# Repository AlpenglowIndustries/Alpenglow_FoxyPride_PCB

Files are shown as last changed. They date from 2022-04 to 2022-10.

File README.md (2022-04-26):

# Foxy_Pride_PCB
An awesome SMT soldering board with space for writing pronouns, where you can choose your own pride-themed colors for the LEDs.
The circuit uses a 555 timer to create a clock signal, which is fed into the decade counter to light the LEDs.
You can change the blink rate by swapping out the capacitor!

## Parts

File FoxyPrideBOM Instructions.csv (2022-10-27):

Id | Designator | Package | Qty Kit | Qty | Description | Manufacturer | Manufacturer Part Number
1 | BT1, | Alpenglow:BatteryHolder_CR2032_SMT | 1 | 1 | Battery holder, side slide style, smt | Hongkong RTL | BK-912
2 | C1, C3, | C_SMD:R_1206_3216Metric_Pad1.30x1.75mm_HandSolder | 2 | 2 | 0.01 uF / 10 nF ceramic chip capacitor, 50V X7R ±10% 1206 | CCTC | TCC1206X7R103K500DTS
3 | C2, C4, | C_SMD:R_1206_3216Metric_Pad1.30x1.75mm_HandSolder | 2 | 2 | 0.1 uF / 100 nF ceramic chip capacitor, 50V X7R ±20% 1206 | CCTC | TCC1206X7R104M500DT
4 | D1, D2, D3, D4, D5, D6, D7, D8, D9, D10, | Alpenglow:LED_1206+ | 5 | 1 | White LED, 25mA 90mcd 2.8V 13700K~19000K Yellow -30℃~+85℃ Positive post White light 120° 80mW 1206 | XINGLIGHT | XL-3216UWC
5 |  | Alpenglow:LED_1206+ | 5 | 1 | Yellow LED, 25mA 130mcd 2.1V 593nm Colorless transparence -30℃~+85℃ 589nm~591nm Positive post yellow 120° 55mW 1206 | XINGLIGHT | XL-3216UYC
6 |  | Alpenglow:LED_1206+ | 5 | 1 | Blue LED, 25mA 60mcd 2.8V 475nm Colorless transparence -30℃~+85℃ Positive post 460nm~469nm blue 120° 80mW 1206 | XINGLIGHT | XL-3216UBC
7 |  | Alpenglow:LED_1206+ | 5 | 1 | Orange LED, 25mA 90mcd 2.1V 605nm Colorless transparence -30℃~+85℃ 601nm~603nm Positive post Orange 120° 55mW 1206 | XINGLIGHT | XL-3216UOC
8 |  | Alpenglow:LED_1206+ | 5 | 1 | Red LED, 25mA 45mcd 1.95V 623nm Colorless transparence -30℃~+85℃ Positive post 617nm~621nm Red 120° 55mW 1206 | XINGLIGHT | XL-3216SURC
9 |  | Alpenglow:LED_1206+ | 5 | 1 | Green LED, 25mA 173mcd 2.9V 534nm Colorless transparence 516nm~525nm -30℃~+85℃ Positive post Emerald 120° 80mW 1206 | XINGLIGHT | XL-3216UGC
10 |  | Alpenglow:LED_1206+ | 5 | 1 | Purple LED | XIASONGXIN LIGHT | SX-1206-5-COLOR
11 |  | Alpenglow:LED_1206+ | 5 | 2 | Pink LED | XIASONGXIN LIGHT | SX-1206-PINK
12 |  | Alpenglow:LED_1206+ | 5 | 1 | Ice Blue / cyan LED | XIASONGXIN LIGHT | 1206 ICE BLUE
13 | R11 | R_SMD:R_1206_3216Metric_Pad1.30x1.75mm_HandSolder | 2 | 2 | 10.0M ohm 1% chip resistor, 1206 | FOJAN | FRC1206F1005TS
14 | R12 | R_SMD:R_1206_3216Metric_Pad1.30x1.75mm_HandSolder | 2 | 2 | 2.20M ohm 1% chip resistor, 1206 | FOJAN | FRC1206F2204TS
15 | R1, R2, R3, R4, R5, R6, R7, R8, R9, R10 | R_SMD:R_1206_3216Metric_Pad1.30x1.75mm_HandSolder | 10 | 8 | 1.00k ohm 1% chip resistor, 1206 | FOJAN | FRC1206F1001TS
16 |  | R_SMD:R_1206_3216Metric_Pad1.30x1.75mm_HandSolder | 10 | 2 | 470 ohm 1% chip resistor, 1206 | YAGEO | RC1206FR-07470RL
17 | S1, | Alpenglow:SW_SPDT_SMT_RTA | 2 | 1 | SPDT slide switch, right angle, SMT | Daier | MSK-12C02
18 | U1, | Alpenglow:SO-8 | 1 | 1 | TLC555CDR, 555 timer in SO-8 pkg | Texas Instruments | TLC555CDR
19 | U2, | Alpenglow:SO-16 | 1 | 1 | 74HC4017D, decade counter in SO-16 pkg | Nexperia | 74HC4017D,653
20 |  |  | 2 | 0 | CR2016 batteries | WANZELONYO | CR2016
21 |  |  | 1 | 0 | Adhesive-backed pin | Pengxiaomei, Hugesavings | B07D5THSLM
22 |  |  | 1 |  | PCB, after dark
 |  |  | 1 |  | PCB, purple
 | *we give you extra of each color of LEDs. It's up to you to decide how many of each color you want.

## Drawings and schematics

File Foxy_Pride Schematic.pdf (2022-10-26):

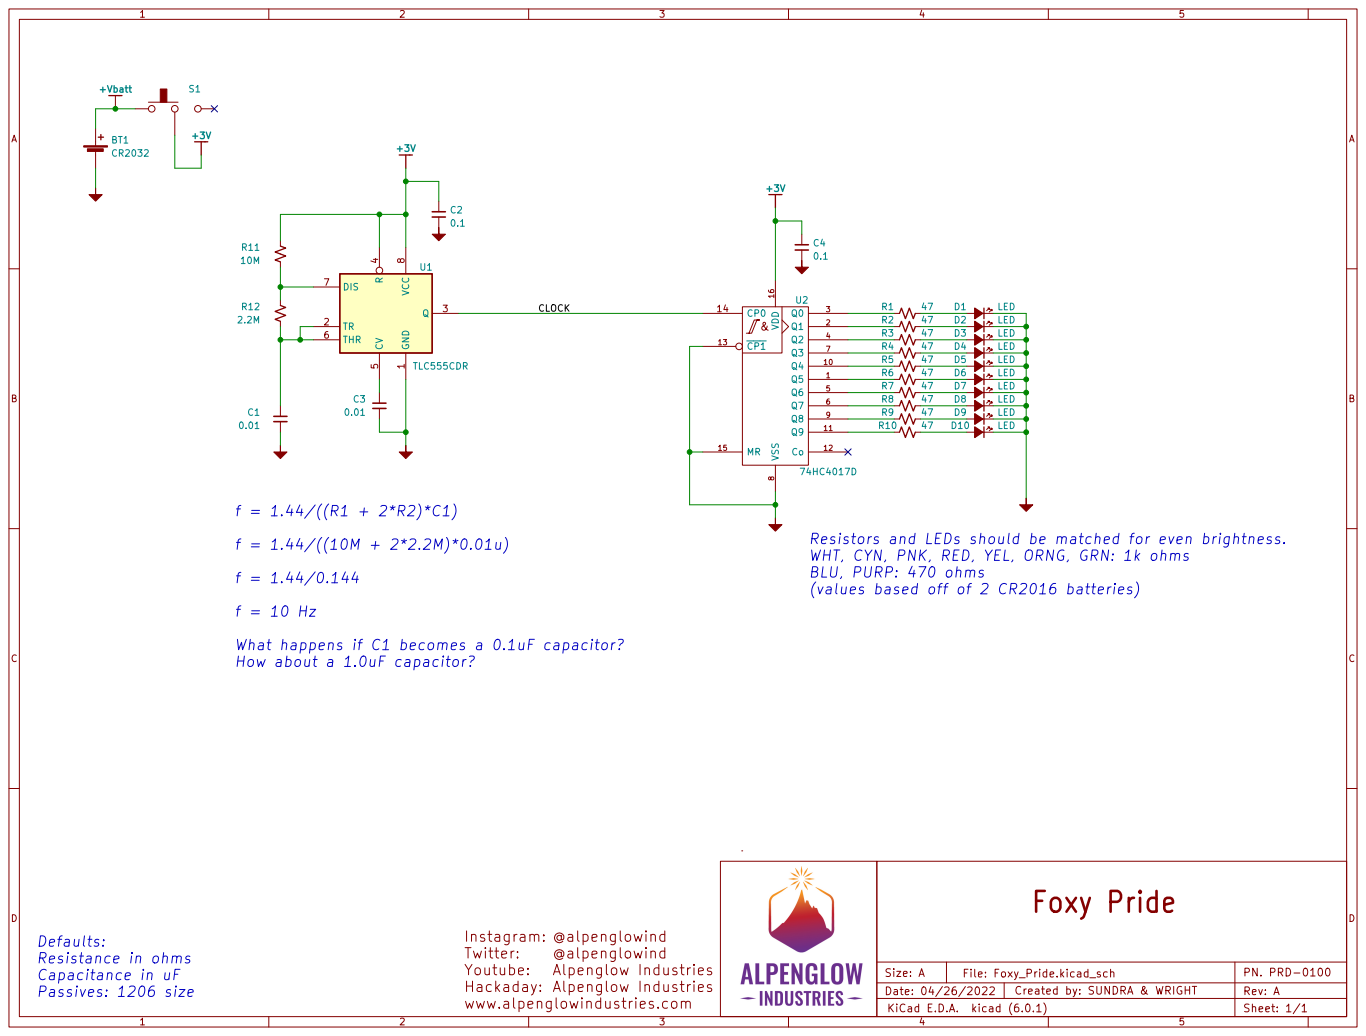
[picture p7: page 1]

Resistors and LEDs should be matched for even brightness.
WHT, CYN, PNK, RED, YEL, ORNG, GRN: 1k ohms
BLU, PURP: 470 ohms
(values based off of 2 CR2016 batteries)

What happens if C1 becomes a 0.1uF capacitor?
How about a 1.0uF capacitor?

www.alpenglowindustries.com Alpenglow Industries | Alpenglow Industries | Sheet: 1/1 Foxy Pride

Size: A
Date: 04/26/2022 KiCad E.D.A. kicad (6.0.1) | | | Rev: A

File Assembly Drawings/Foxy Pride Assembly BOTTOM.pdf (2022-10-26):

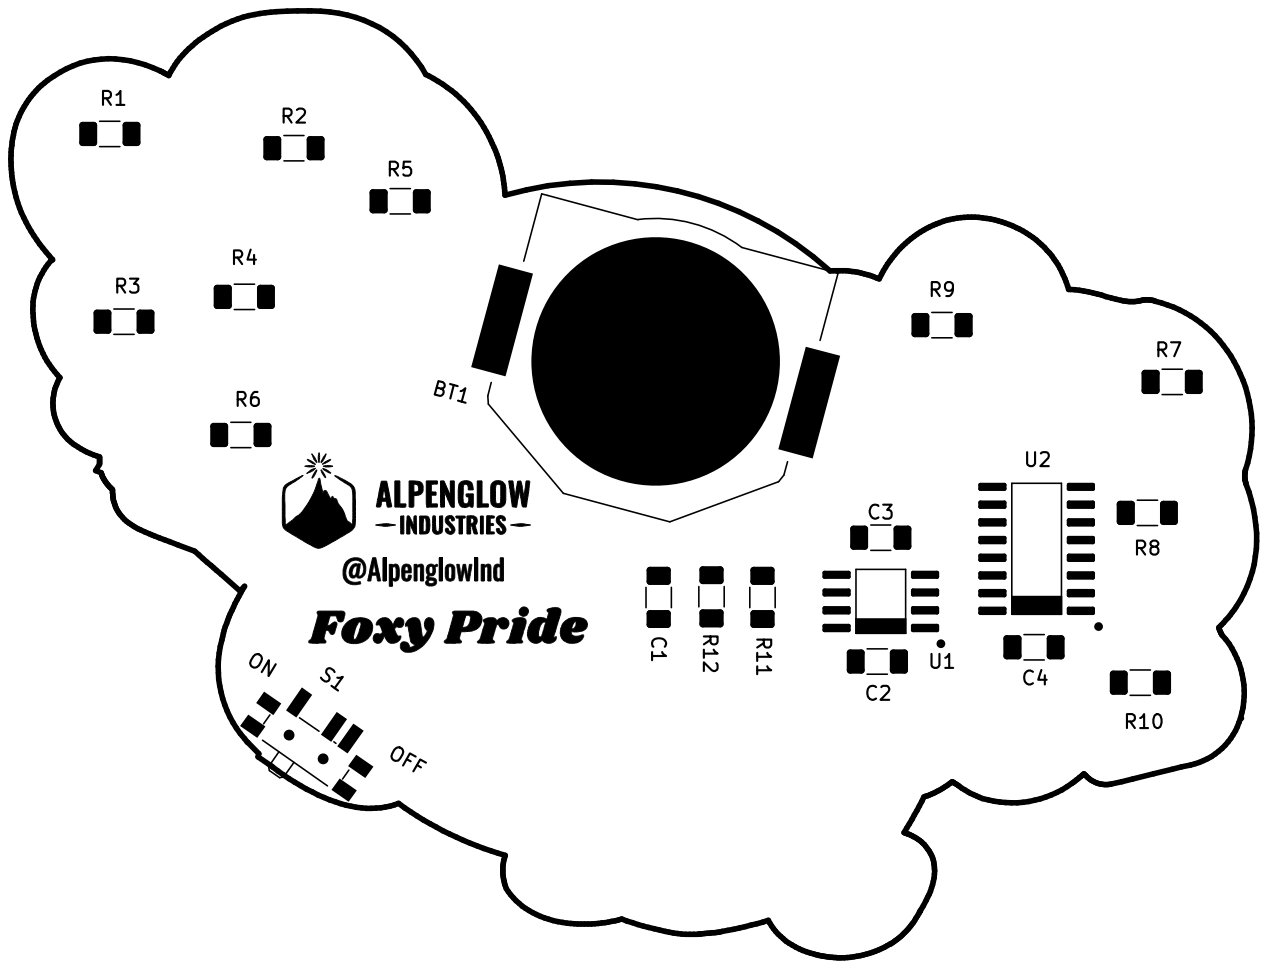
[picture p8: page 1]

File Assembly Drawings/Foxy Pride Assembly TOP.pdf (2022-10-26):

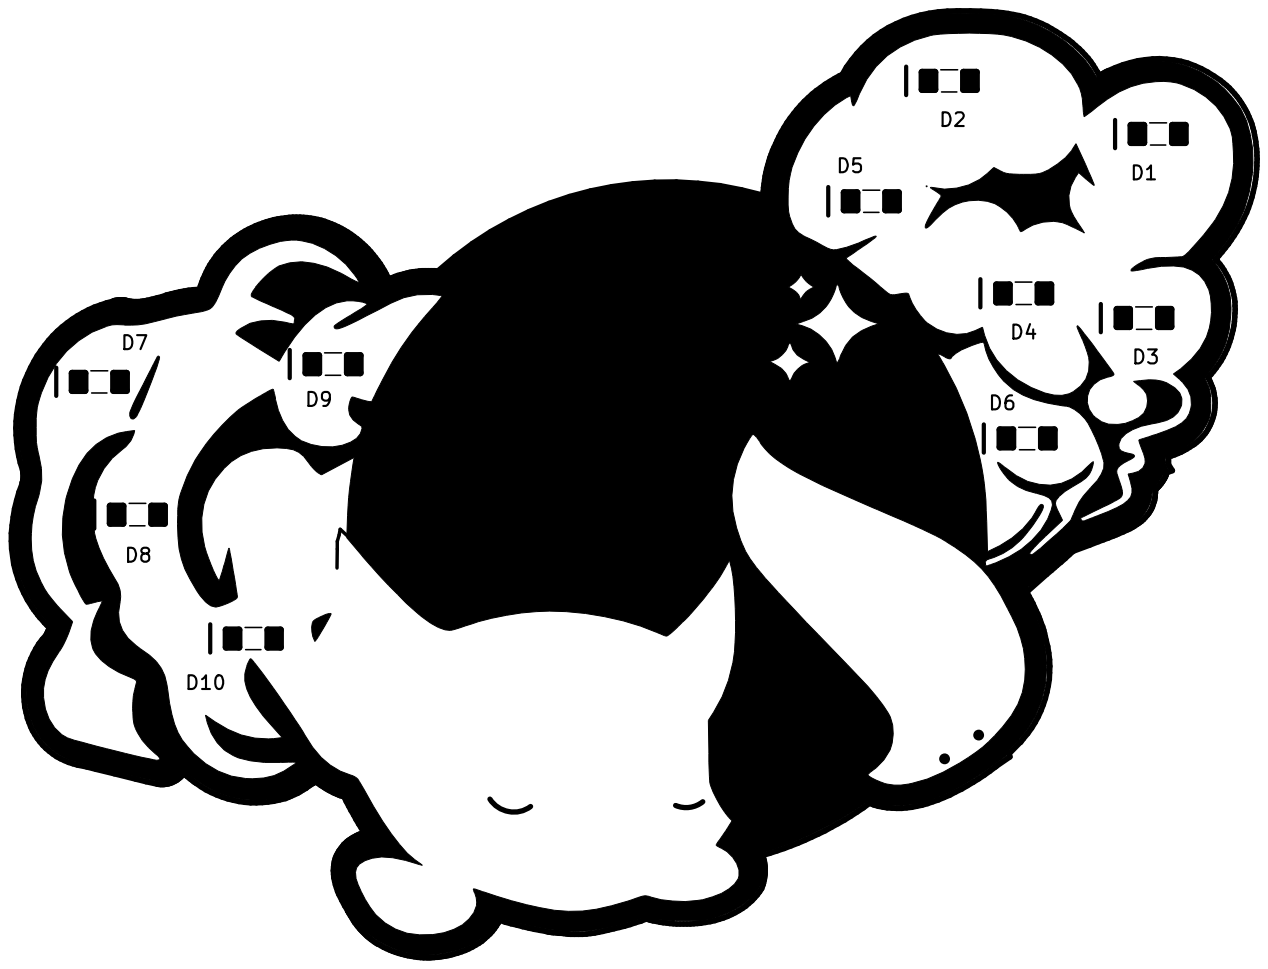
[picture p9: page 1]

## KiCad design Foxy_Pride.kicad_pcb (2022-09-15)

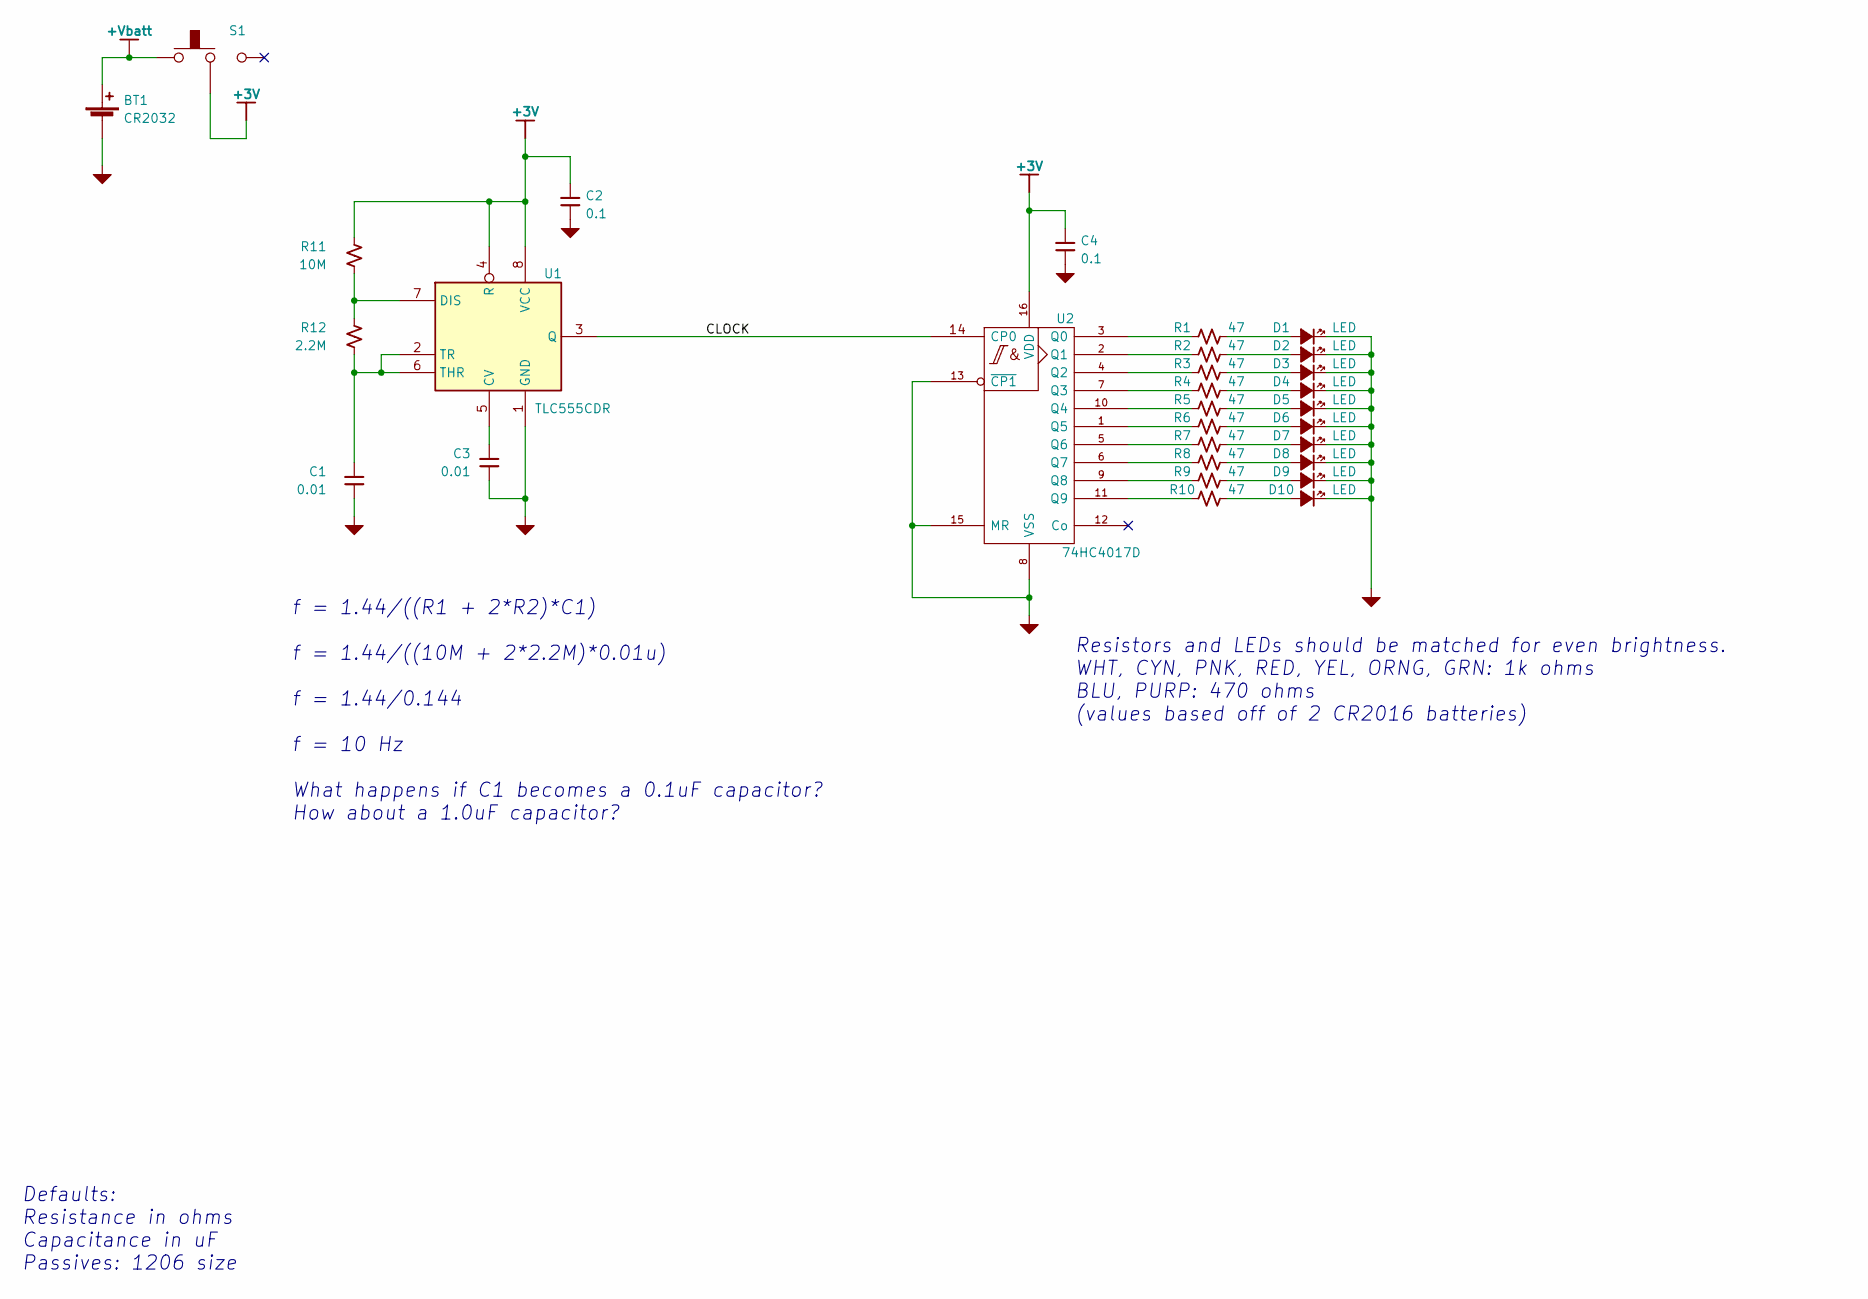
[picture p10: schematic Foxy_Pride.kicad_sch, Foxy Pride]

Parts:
BT1: CR2032; BatteryHolder_CR2032_SMT
C1, C3: 0.01; R_1206_3216Metric_Pad1.30x1.75mm_HandSolder
C2, C4: 0.1; R_1206_3216Metric_Pad1.30x1.75mm_HandSolder
D1, D2, D3, D4, D5, D6, D7, D8, D9, D10: LED; LED_1206+
R1, R2, R3, R4, R5, R6, R7, R8, R9, R10: 47; R_1206_3216Metric_Pad1.30x1.75mm_HandSolder
R11: 10M; R_1206_3216Metric_Pad1.30x1.75mm_HandSolder
R12: 2.2M; R_1206_3216Metric_Pad1.30x1.75mm_HandSolder
S1: SMT_Slide_Switch; SW_SPDT_SMT_RTA
U1: TLC555CDR; SO-8
U2: 74HC4017D; SO-16

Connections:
+3V: C2.1, C4.1, R11.1, S1.2, U1.4 (R), U1.8 (VCC), U2.16 (VDD)
+Vbatt: BT1.1 (+), S1.1
/CLOCK: U1.3 (Q), U2.14 (CP0)
GND: BT1.2 (-), C1.2, C2.2, C3.2, C4.2, D1.1 (K), D2.1 (K), D3.1 (K), D4.1 (K), D5.1 (K), D6.1 (K), D7.1 (K), D8.1 (K), D9.1 (K), D10.1 (K), U1.1 (GND), U2.8 (VSS), U2.13 (~CP1), U2.15 (MR)
unnamed: C1.1, R12.2, U1.2 (TR), U1.6 (THR)
unnamed: C3.1, U1.5 (CV)
unnamed: D1.2 (A), R1.1
unnamed: D2.2 (A), R2.1
unnamed: D3.2 (A), R3.1
unnamed: D4.2 (A), R4.1
unnamed: D5.2 (A), R5.1
unnamed: D6.2 (A), R6.1
unnamed: D7.2 (A), R7.1
unnamed: D8.2 (A), R8.1
unnamed: D9.2 (A), R9.1
unnamed: D10.2 (A), R10.1
unnamed: R1.2, U2.3 (Q0)
unnamed: R2.2, U2.2 (Q1)
unnamed: R3.2, U2.4 (Q2)
unnamed: R4.2, U2.7 (Q3)
unnamed: R5.2, U2.10 (Q4)
unnamed: R6.2, U2.1 (Q5)
unnamed: R7.2, U2.5 (Q6)
unnamed: R8.2, U2.6 (Q7)
unnamed: R9.2, U2.9 (Q8)
unnamed: R10.2, U2.11 (Q9)
unnamed: R11.2, R12.1, U1.7 (DIS)

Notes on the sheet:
Defaults: Resistance in ohms Capacitance in uF Passives: 1206 size
f = 1.44/((R1 + 2*R2)*C1) f = 1.44/((10M + 2*2.2M)*0.01u) f = 1.44/0.144 f = 10 Hz What happens if C1 becomes a 0.1uF capacitor? How about a 1.0uF capacitor?
Resistors and LEDs should be matched for even brightness. WHT, CYN, PNK, RED, YEL, ORNG, GRN: 1k ohms BLU, PURP: 470 ohms (values based off of 2 CR2016 batteries)

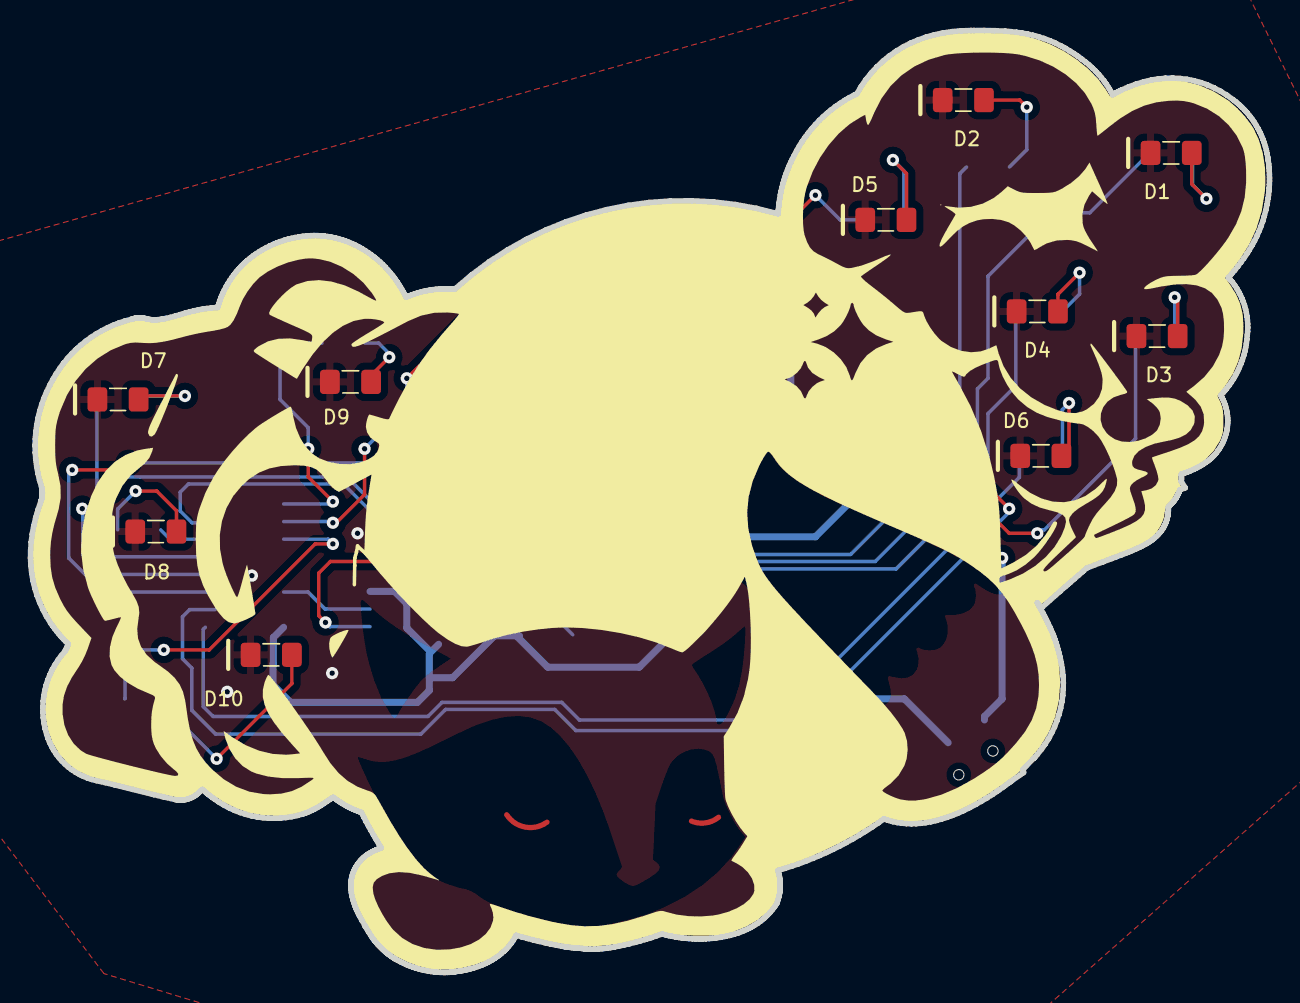
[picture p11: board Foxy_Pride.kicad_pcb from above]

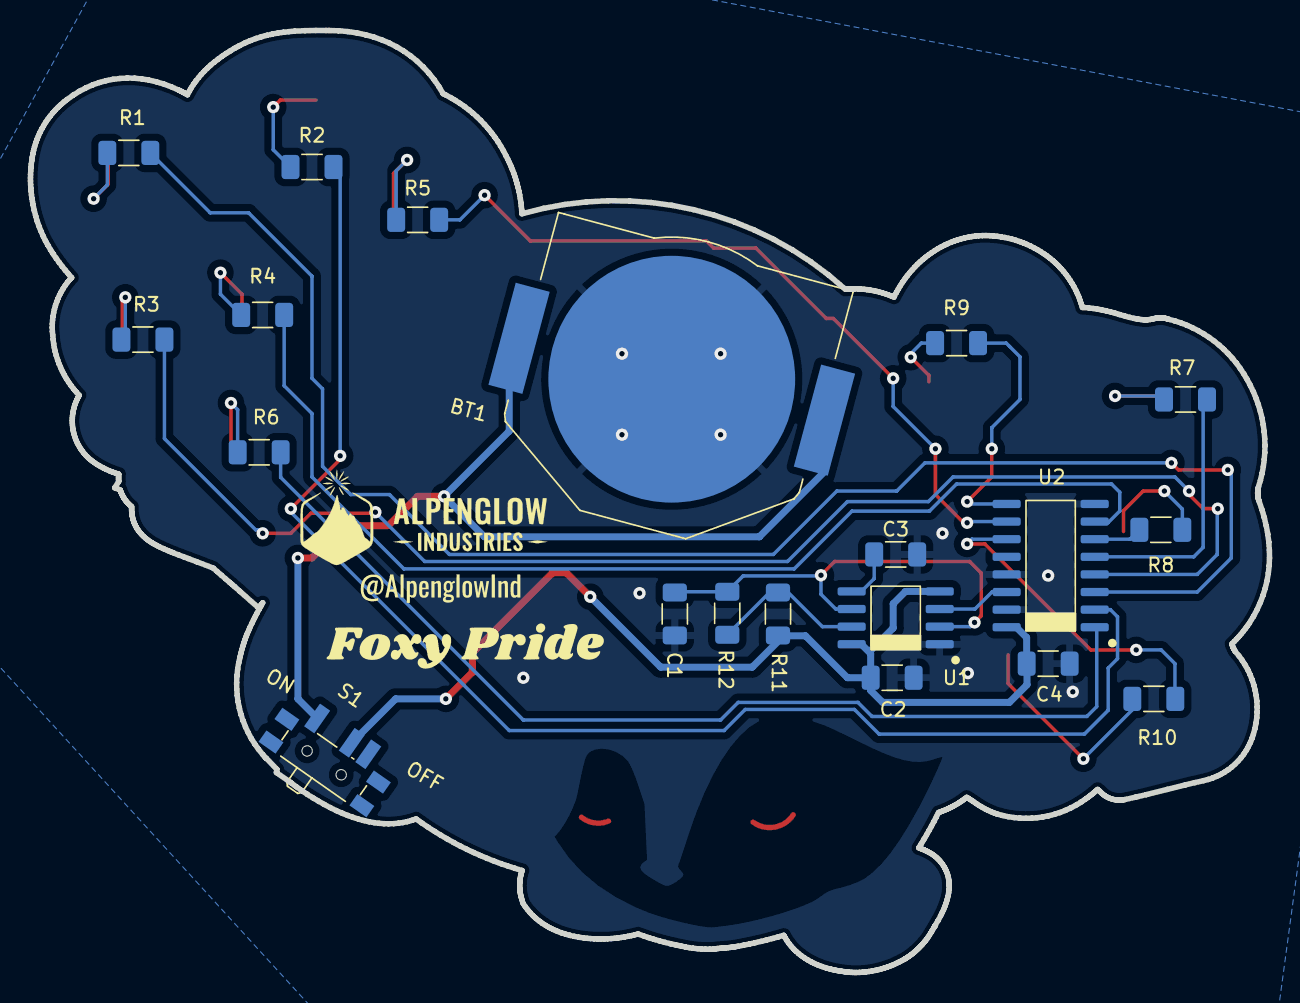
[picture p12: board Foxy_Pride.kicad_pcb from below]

Board: 2 copper layers, 89.3 x 67.9 mm, 30 parts (20 on the bottom side), 27 nets.

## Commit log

2022-04-26 initial commit of files
    [Foxy_Pride.kicad_pcb, Foxy_Pride.kicad_sch]
2022-04-29 PCB layout editing
    [Alpenglow_FoxyPride_PCB.kicad_pcb, Foxy_Pride.kicad_pcb, Foxy_Pride.kicad_sch]
2022-05-02 PCB Layout
    [Foxy_Pride.kicad_pcb, Foxy_Pride.kicad_sch]
2022-05-03 Added vias to connect GND
    [Foxy_Pride.kicad_pcb]
2022-05-03 changes to make some routing shorter, fixed switch and power, added eyes in copper
    [Foxy_Pride.kicad_pcb]
2022-05-04 Finalized design and layout on Foxy Pride PCB
    [Foxy_Pride-B_Cu.gbr, Foxy_Pride-B_Mask.gbr, Foxy_Pride-B_Silkscreen.gbr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]
2022-05-06 Deleted unused files
    [Alpenglow_FoxyPride_PCB.kicad_pcb, Foxy_Pride.kicad_pcb]
2022-05-17 Re annontated schematic so resistors and LEDs have matching refrence designators
    [Foxy_Pride.kicad_pcb, Foxy_Pride.kicad_sch]
2022-05-19 Changed schematic layout. Put resistor in correct spot. Update PCB.
    [Foxy_Pride.kicad_pcb, Foxy_Pride.kicad_sch]
2022-05-19 Repositioned resistor and capacitor
    [Foxy_Pride.kicad_pcb, Foxy_Pride.kicad_sch]
2022-05-23 Update 555 timer footprint and decasde counter. had to fix a couple tranes after.
    [Foxy_Pride.kicad_pcb]
2022-06-01 Updated Final Design
    [Foxy_Pride.kicad_pcb, Foxy_Pride.kicad_sch]
2022-06-03 generated gerbers for ordering
    [Foxy_Pride-B_Cu.gbr, Foxy_Pride-B_Mask.gbr, Foxy_Pride-B_Paste.gbr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]
2022-09-15 Updated board name with font, updated @alpenglowind with font
    [Foxy_Pride.kicad_pcb]
2022-10-24 Generated Schematic PDF
2022-10-26 Assembly drawings, BOM, schematic
    [FoxyPrideBOM Instructions.xlsx]
2022-10-26 Added title block, Updated schematic PDF
2022-10-27 updated BOM
    [FoxyPrideBOM Instructions.xlsx]
2022-10-27 Updated gitignore, changed BOM to CSV file
    [FoxyPrideBOM Instructions.csv, FoxyPrideBOM Instructions.xlsx]
